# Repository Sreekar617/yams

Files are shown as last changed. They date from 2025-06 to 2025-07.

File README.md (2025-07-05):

## Yet Another Metronome by Sreekar  

Usually when I'm practicing my violin, I like to do a lot of metronome work to keep myself on tempo. However, neither my phone nor my laptop can be heard above the sound of the violin, and it's generally not a good idea to practice quieter because you practice the way you perform.  

Up until this point, my solution was to use the metronome on a Roland Digital Piano, since they're super loud and available for use at my school, where I do most of my practice. The problem is, I don't always practice in the practice rooms, and even then, the rooms with the piano aren't always available.  

My solution is to make a small, portable metronome that can stil get loud enough to hear over my violin playing. The device contains a piezo buzzer, a single Neopixel for visual feedback, an OLED to see the current BPM, and a rotary encoder to change the BPM. To keep things light and small, it's powered by a XIAO RP2040. 

PCB                             |  PCB + Case
:------------------------------:|:---------------------------------:
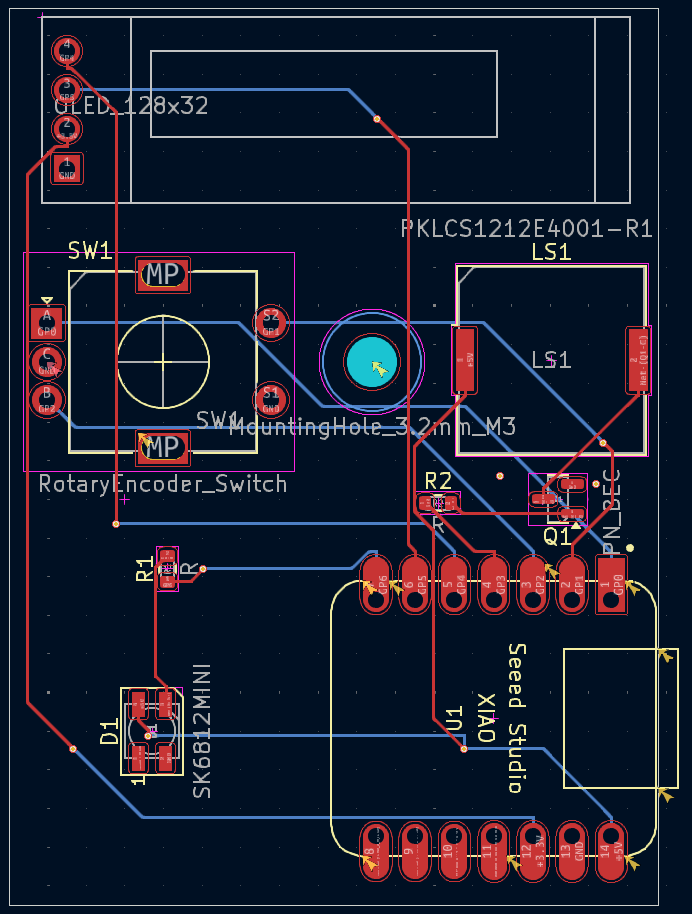
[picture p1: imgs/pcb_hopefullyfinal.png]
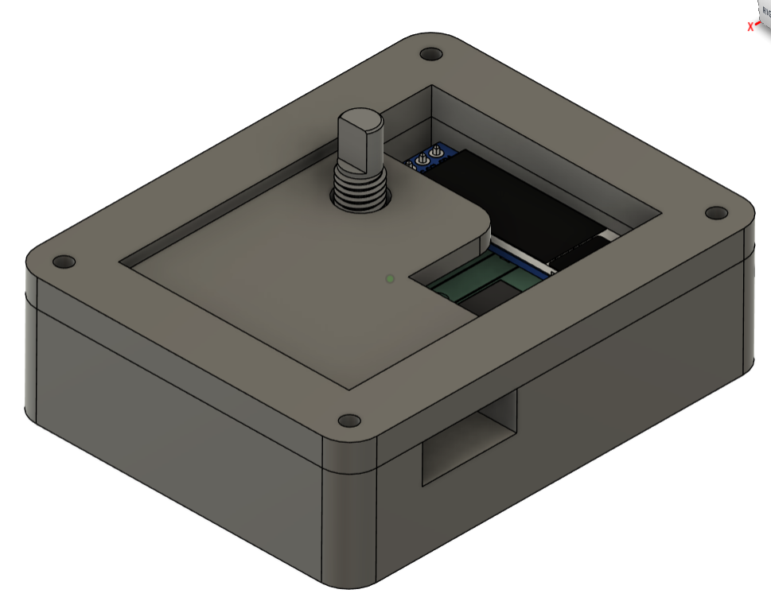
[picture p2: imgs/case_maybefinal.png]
full
| 

BOM:
| Id | Designator | Footprint | Quantity | Designation | Supplier and ref | Link |
| -- | --- | --- | --- | --- | --- | --- |
| 1  | D1 | LED_SK6812MINI_PLCC4_3.5x3.5mm_P1.75mm | 1 | SK6812MINI | C5149201 | https://jlcpcb.com/partdetail/OPSCOOptoelectronics-SK6812MINIE/C5149201  |
| 2  | Q1 | SOT-23 | 1 | Q_NPN_BEC | C2150 | https://jlcpcb.com/partdetail/2507-SS8050_RANGE_200_350/C2150 |
| 3  | J1 | OLED_128x32 | 1 | OLED_128x32 | C5248081 | https://jlcpcb.com/partdetail/HS-HS91L02W2C01/C5248081 |
| 4  | SW1 | RotaryEncoder_Alps_EC11E-Switch_Vertical_H20mm | 1 | RotaryEncoder_Switch  | C202365 | https://jlcpcb.com/partdetail/ALPSALPINE-EC11E18244AU/C202365 |
| 5  | R1 | R_0603_1608Metric | 1 | 300Ω | C23025 | https://jlcpcb.com/partdetail/23752-0603WAF3000T5E/C23025 |
| 6  | R2 | R_0603_1608Metric | 1 | 1000Ω | C51218 | https://jlcpcb.com/partdetail/52231-0603WAD1001T5E/C51218 |
| 7  | U1 | XIAO-Generic-Hybrid-14P-2.54-21X17.8MM | 1 | MOUDLE-SEEEDUINO-XIAO | | https://www.seeedstudio.com/XIAO-RP2040-v1-0-p-5026.html |
| 8  | LS1 | Buzzer_Murata_PKLCS1212E | 1 | PKLCS1212E4001-R1 | C113159 | https://jlcpcb.com/partdetail/MurataElectronics-PKLCS1212E4001R1/C113159 |
| 9  | -- | -- | 4 | M3x20mm Screws | Generic | Source locally |
| 10 | -- | -- | 1 | M3x12mm Screw | Generic | Source locally |
| 11 | -- | -- | 5 | M3 Nuts | Generic | Source locally |
| 12 | -- | -- | 1 | Bottom Case | Generic | Print with Legion |
| 13 | -- | -- | 1 | Top Case | Generic | Print with Legion |
| 14 | -- | -- | 1 | PCB | JLCPCB | Order from JLCPCB |

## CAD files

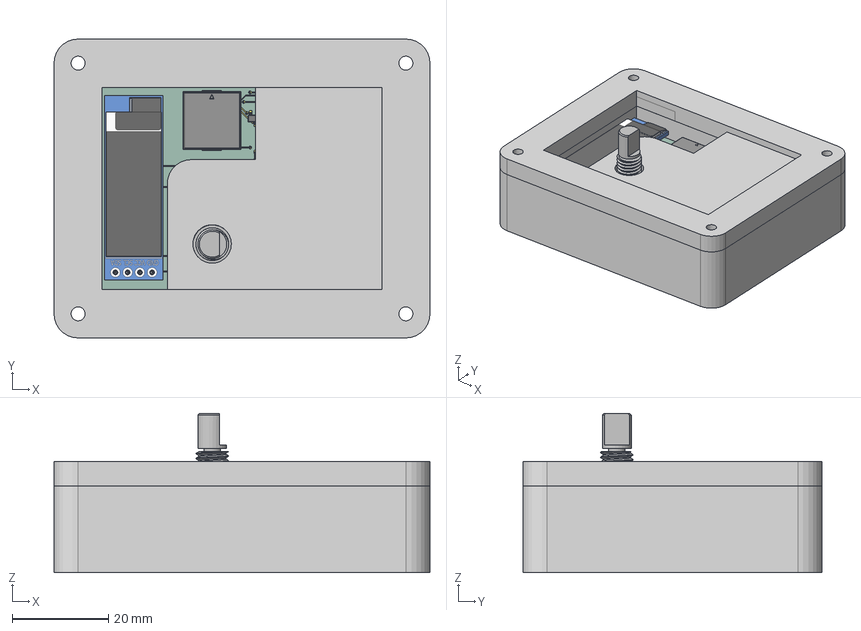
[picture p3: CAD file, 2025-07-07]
CAD/yams_full.step
78.0 x 62.0 x 33.0 mm
SK6812_Mini_1
SK6812_Mini004
SK6812_Mini003
SK6812_Mini005
SK6812_Mini002
SK6812_Mini001
SOT-23
OLED_0.91_128x32
Pin Header 4 x 1 TH 2.54mm Pitch
RESC-0603 x 13
2SD0601A
æè½¬ç¼ç å¨
R_0603_1608Metric x 2
PKLCS1212E4001-R1--3DModel-STEP-56544
yams_metronome_copper
yams_metronome_PCB
type-c v2
smd_button v3
DOUT
DIN
VSS
VDD
smd_button v3(Mirror)

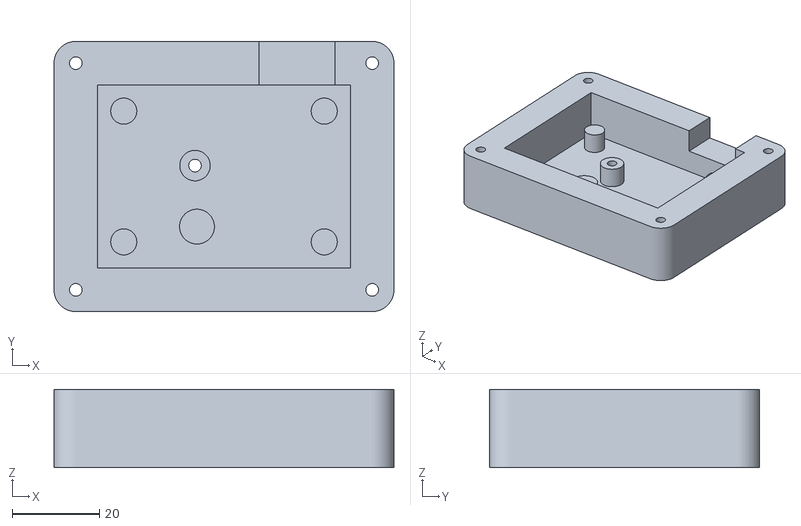
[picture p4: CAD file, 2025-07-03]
production/yams_case_bottom.stl
78.0 x 62.0 x 18.0

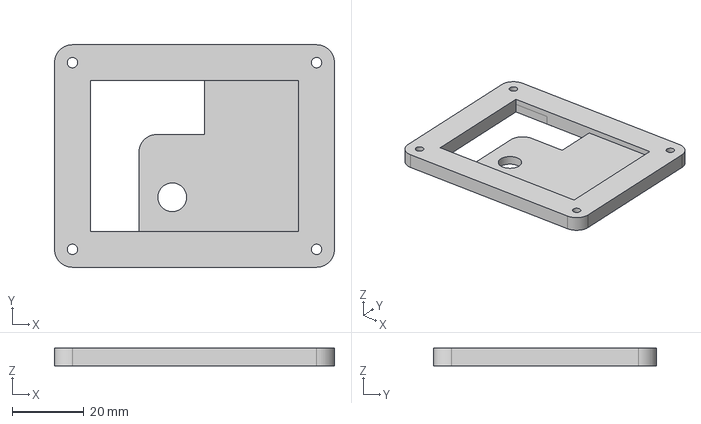
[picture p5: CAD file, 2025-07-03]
CAD/yams_case_top.step
78.0 x 62.0 x 5.00 mm

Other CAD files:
production/yams_case_top.stl
CAD/yams_case_bottom.step

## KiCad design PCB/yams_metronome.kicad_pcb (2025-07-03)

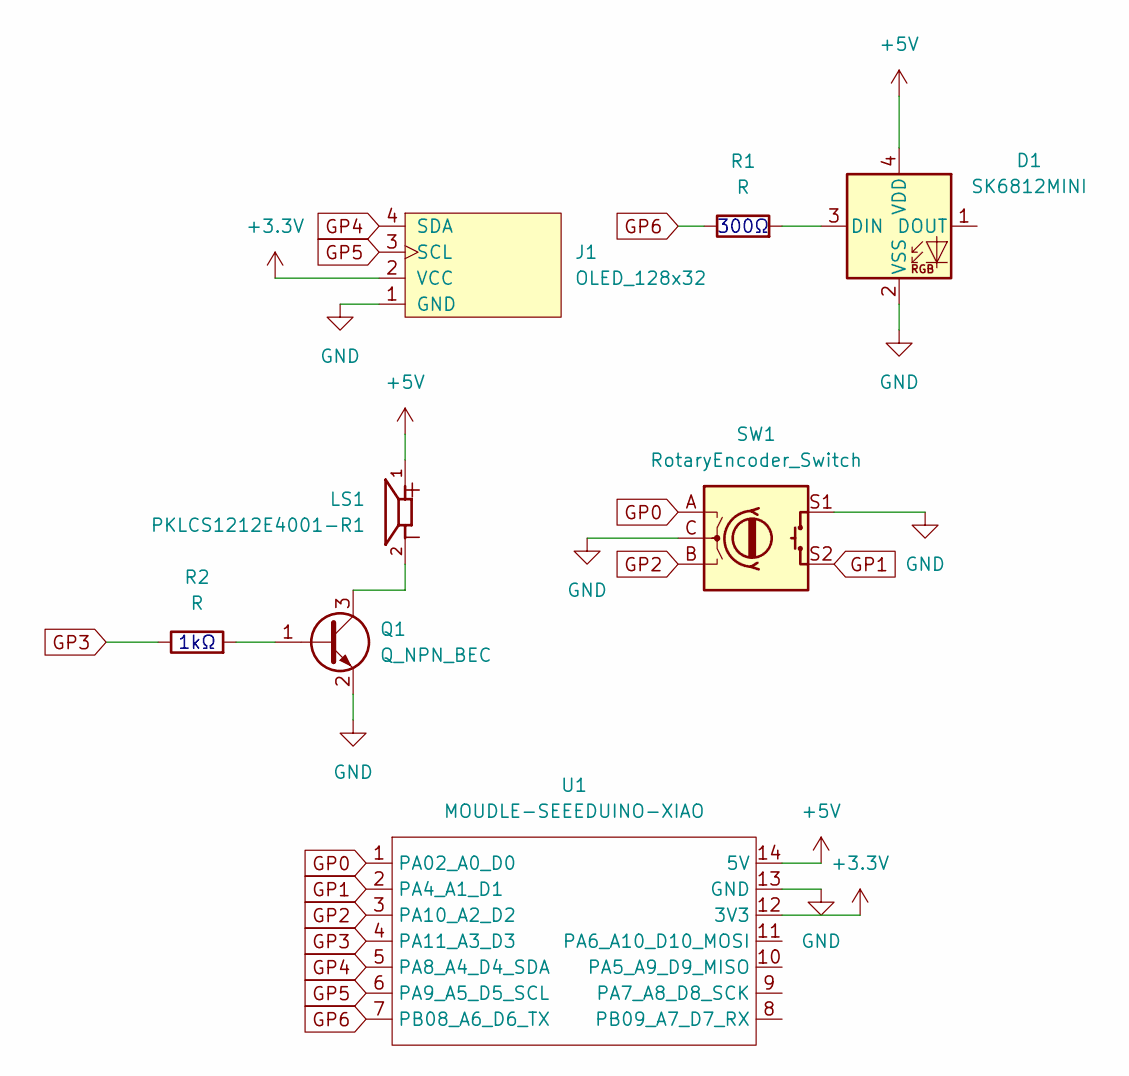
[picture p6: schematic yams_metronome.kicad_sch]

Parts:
D1: SK6812MINI; LED_SK6812MINI_PLCC4_3.5x3.5mm_P1.75mm
J1: OLED_128x32
LS1: PKLCS1212E4001-R1; Buzzer_Murata_PKLCS1212E; PARTREV January 22, 2018
Q1: Q_NPN_BEC; SOT-23
R1, R2: R; R_0603_1608Metric
SW1: RotaryEncoder_Switch; RotaryEncoder_Alps_EC11E-Switch_Vertical_H20mm
U1: MOUDLE-SEEEDUINO-XIAO; XIAO-Generic-Hybrid-14P-2.54-21X17.8MM

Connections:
+3.3V: J1.2 (VCC), U1.12 (3V3)
+5V: D1.4 (VDD), LS1.1, U1.14 (5V)
GND: D1.2 (VSS), J1.1 (GND), Q1.2 (E), SW1.C, SW1.S1, U1.13 (GND)
GP0: SW1.A, U1.1 (PA02_A0_D0)
GP1: SW1.S2, U1.2 (PA4_A1_D1)
GP2: SW1.B, U1.3 (PA10_A2_D2)
GP3: R2.1, U1.4 (PA11_A3_D3)
GP4: J1.4 (SDA), U1.5 (PA8_A4_D4_SDA)
GP5: J1.3 (SCL), U1.6 (PA9_A5_D5_SCL)
GP6: R1.1, U1.7 (PB08_A6_D6_TX)
unnamed: D1.3 (DIN), R1.2
unnamed: Q1.1 (B), R2.2
unnamed: LS1.2, Q1.3 (C)

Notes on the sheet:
300Ω
1kΩ

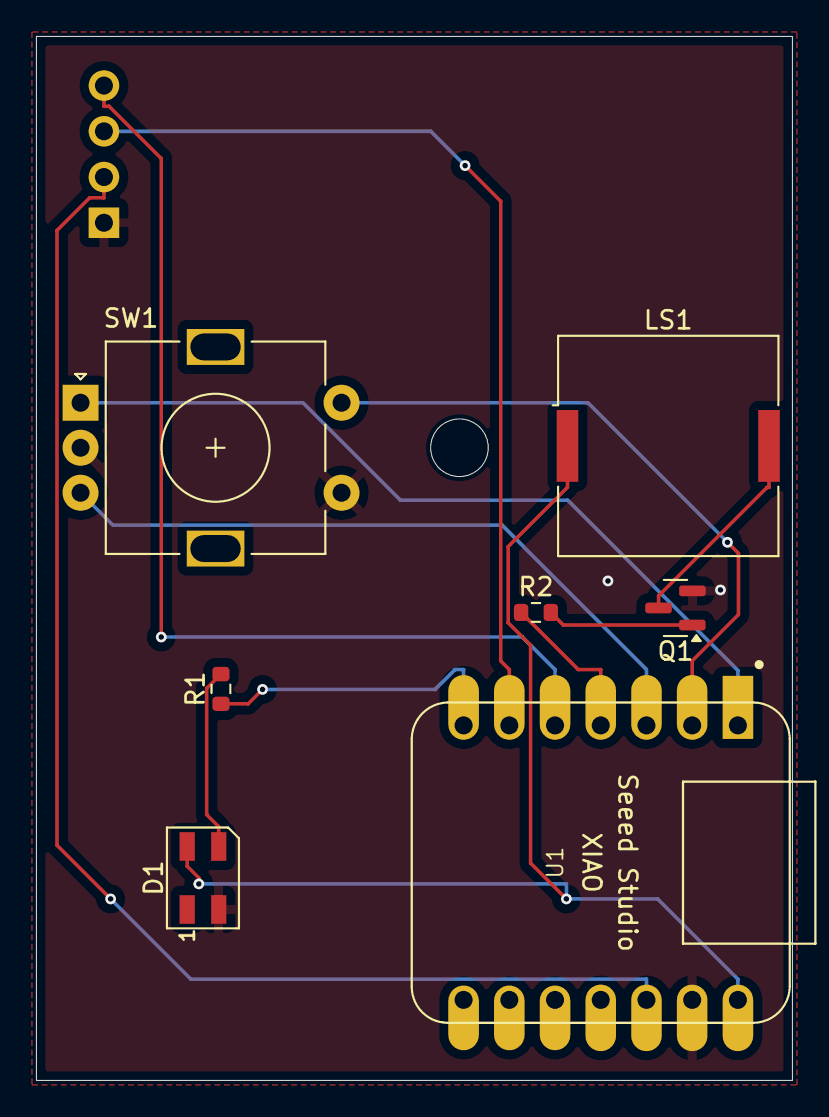
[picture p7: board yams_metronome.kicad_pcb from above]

Board: 2 copper layers, 42.0 x 58.0 mm, 8 parts (0 on the bottom side), 13 nets.

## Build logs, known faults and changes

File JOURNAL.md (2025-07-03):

---
title: "Yet Another Metronome by Sreekar"
author: "Sreekar Ramisetty"
description: "Metronome with rotary encoder and OLED display"
created_at: "2024-06-04"
---
# total time: 18 hours

## June 4th, 2025, 6:32 PM<br>
I have a vision for where I want to take this project, but since I have finals tomorrow i'll just get a basic schematic whipped up (i have no idea what i'm doing)<br>
**literally like 30 seconds spent 😭**

## June 9th, 2025, 3:17 PM<br>
I did not in fact get anything done but finals are over so i can probably actually get started today<br>
hear me out tabletop flat design cause i'm scared of 90°, plate for mx switches and an oled cause i'm overconfident, but first let's get a basic pcb done<br>
wait no hear me out: rotary encoder. to encode your rotary movement. amirite amirite?<br>
**1 hour spent**

## June 12th, 2025, 9:01 PM<br>
ok time to wire up the oled and rotary encoder<br>
zawg how do i power ts<br>
ohhhh now i know the difference between vsys, vbus, and 3v3<br>
it's all wired in the schematic :yay:<br>
now time to find a speaker that's loud and preferably not expensive (good cheap fast ahh)<br>
oops i had the times i spent written in obsidian but not here better add those in<br>
alr i got a somewhat coherent schematic together i'm going to sleep now<BR>
**2 hours spent**<Br>


## June 13th, 2025 12:04 PM<br>
if you're reading the actual markdown for some reason i must apologize for the way i format this<br>
so i want to put an led on here for visual feedback<br>
i could use just a single led or i could use a neopixel :wow:<br>
i think for the led i could just give it power every x ms and put a resistor in front of it<br>
after further research, i've decided to just use a single neopixel<br>
time to go back to the schematic<br>
**1 hour spent 😭**<Br>


## June 15th, 2025 4:30 PM<br>
i guess it's time to pcb all over the place<br>
nvm my schematic has issues<br>
so i guess it's better to power oled with 3v3<br>
and my neopicel wasn't connected to anything somehow<br>
also i guess the buzzer should also use 3v3, honestly the buzzer is what i'm most worried about<br>
schematic should be finished now, it looks so tuff<br>

oh i guess the pins for the buzzer symbol don't match the ones on the footprint, i guess i should just reassign them<br>
**2 hours spent**

## June 18th, 2025 1:12 PM<br>
i fixed the buzzer and made a basic outline of how i want it on paper and on the pcb<Br>
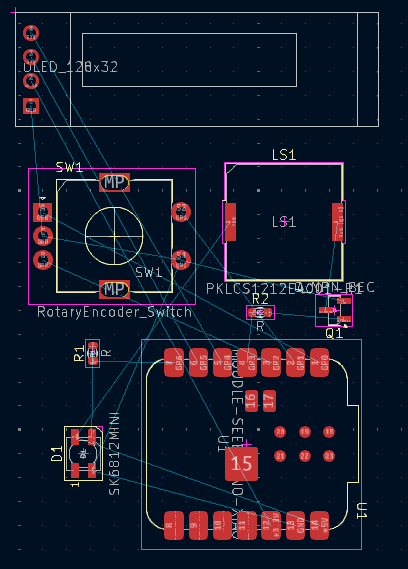
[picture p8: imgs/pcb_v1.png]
<Br>
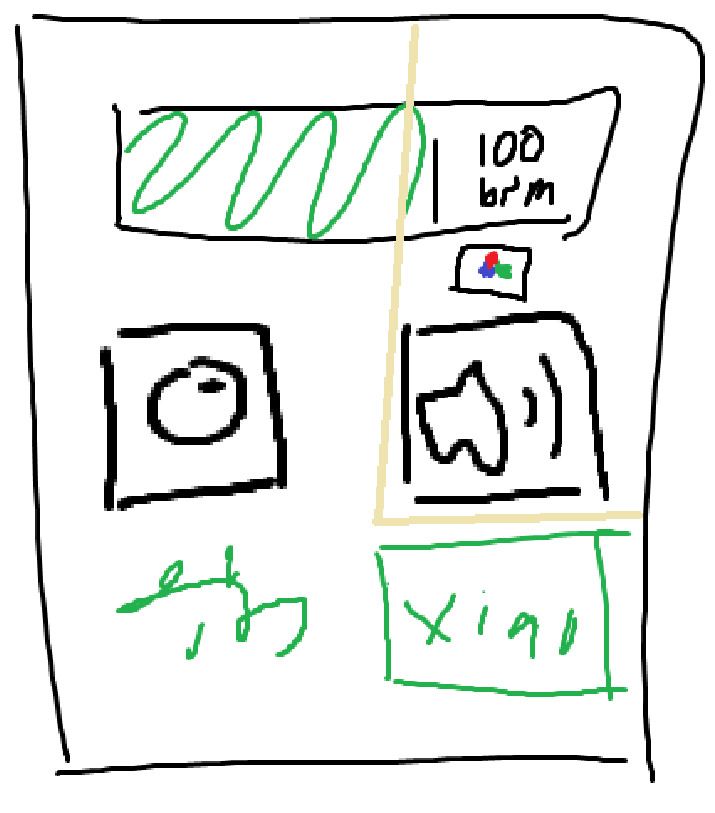
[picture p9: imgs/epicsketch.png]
<br>
**1 hour spent**

## June 22nd, 6:32 PM<Br>
got pcb outline finished and wired
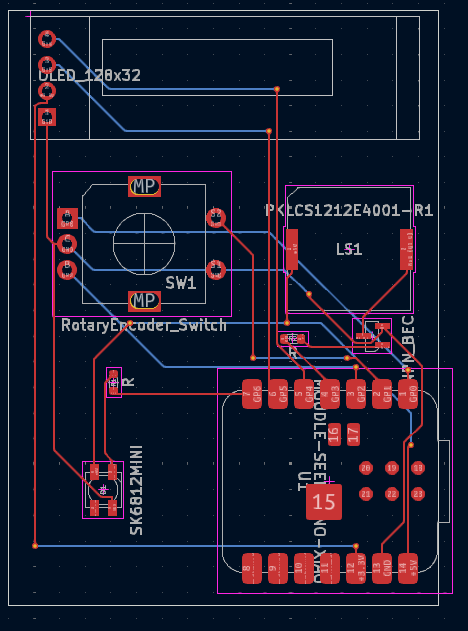
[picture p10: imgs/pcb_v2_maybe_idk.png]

**1 hour spent**

## June 29th, 7:30 PM<br>
ok i should run git push i've been editing ts locally this whole time 😭<br>
anyway i'm locking in now to make the case<br>
okay i think it'll be more stable if i make a round cutout for the rotary encoder instead of just having it completely exposed<br>
and i should also have a square border that is actually connected to the "plate" to give it some more stability<br>
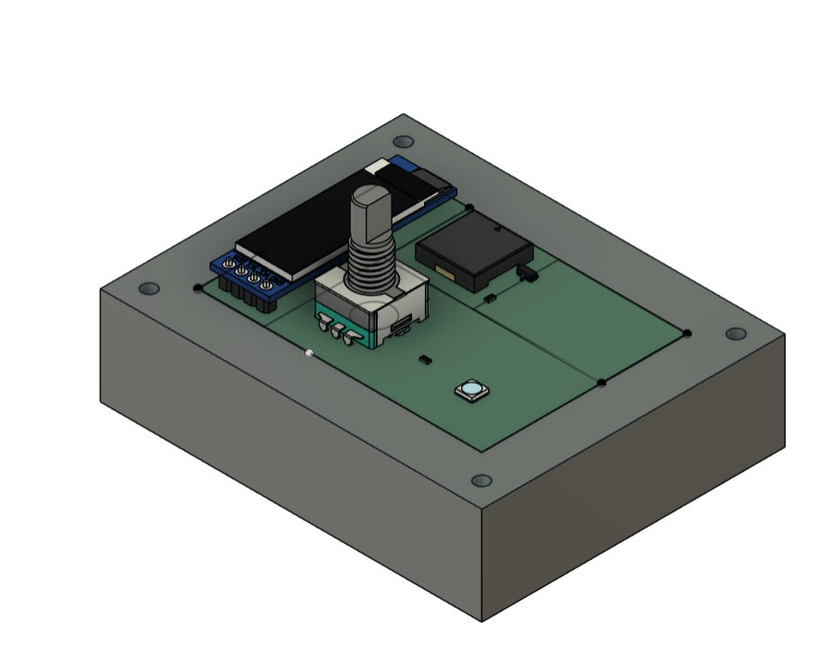
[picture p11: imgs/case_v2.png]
<br>
wait i was going to sandwich mount it like a keyboard but i don't have mx switches, just a rotary encoder<br>
how do i mount ts 😭<br>
**3 hours spent**

## June 30th, 2:34 PM<br>
i thought about it and i looked at the mounting styles website and i think if i make a kind of tray mount style case it'll be fine<br>
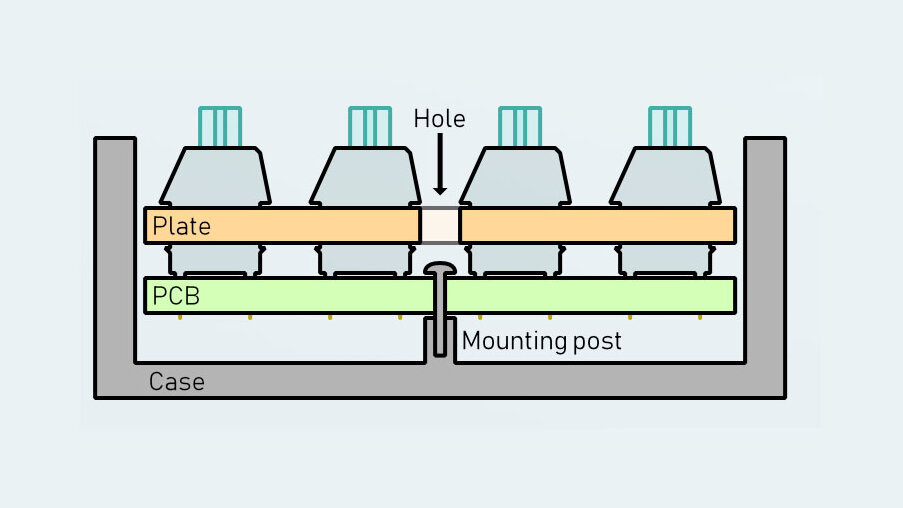
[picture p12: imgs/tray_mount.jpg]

so in my case the "plate" doesn't hold up the pcb in any way, it's just to cover and protect the pcb, so i'll have a couple more posts in the corners to hold it up, and probably something under the encoder to give it stability<br>
i made some slight adjustments to the pcb to give the screw a bit of clearance<br>
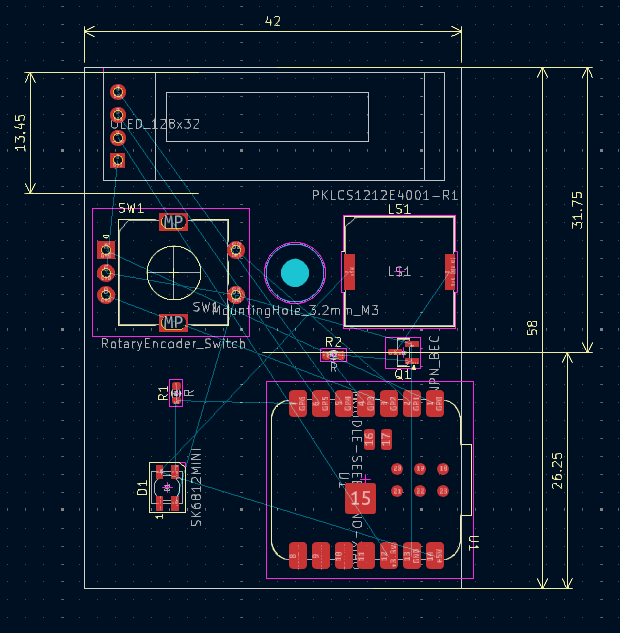
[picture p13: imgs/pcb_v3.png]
<br>
ok i'll just edit my sketch and go to sleep
**2 hours spent**

## July 1st, 3:22 PM<br>
i want to get ts finished today, luckily it's just continuing manual labor from yesterday  
okay i got the case put together  
  
so this is in two pieces, the bottom case and a top covering.  
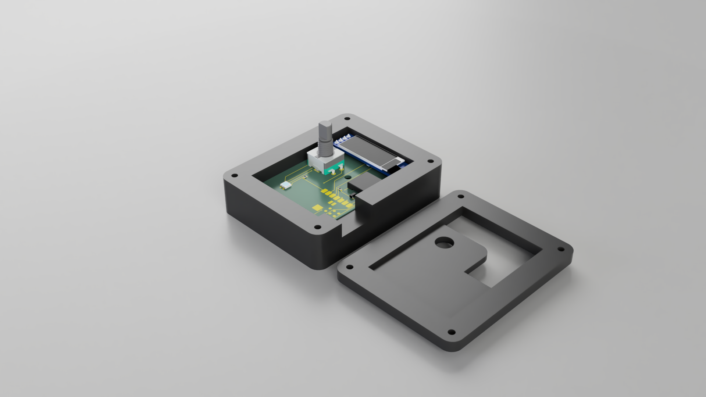
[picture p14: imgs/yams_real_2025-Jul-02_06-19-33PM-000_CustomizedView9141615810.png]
alt extxusdcgfsihguofijdhsu
  
there's a hole for the rotary encoder, and another hole on the side for power delivery to the xiao  
the pcb is held up with supports at the bottom of the case. there's a "post" in each corner, plus one directly under the rotary   encoder and one approximately in the middle to screw into.  
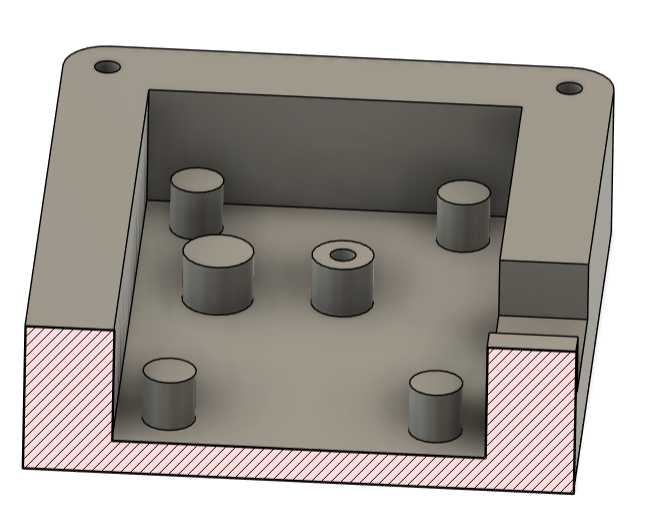
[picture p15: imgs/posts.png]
  
agh i forgot about firmware see you tomorrow  
**2 hours spent**

## July 2st, 1:10 PM<br>
okay firmware should be pretty simple. i think i can even get away with using qmk cause that's what i'm familiar with  
ok so i am definitely not using qmk  
oh yeah i added a ground pour  
  
after much research and docs reading, i think i got a probably working firmware:  
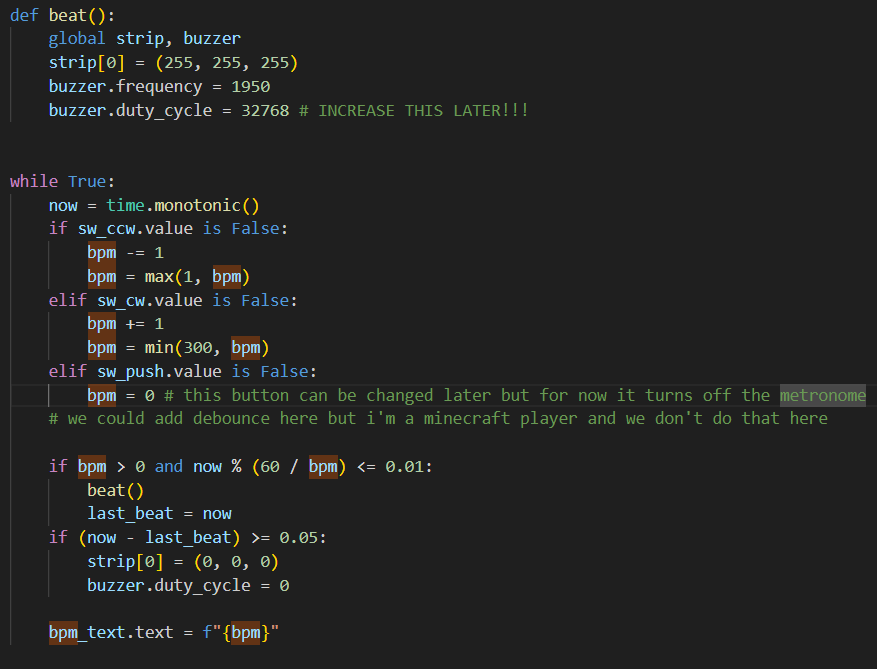
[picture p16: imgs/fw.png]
i aint reading allat
  
you change the bpm with the rotary encoder, and push on it to turn off the metronome  
when a beat happens, the piezo buzzer chirps and the neopixel flashes  
yeah that's pretty much it :heavysob:  
thanks for reading make sure to like and subscribe  
**3 hours spent**

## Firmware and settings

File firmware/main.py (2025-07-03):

import time
import board
import displayio
import terminalio
from adafruit_display_text import label
import adafruit_displayio_ssd1306
import busio
import digitalio
import neopixel
import pwmio

displayio.release_displays()
i2c = busio.I2C(scl=board.GP5, sda=board.GP4)
display_bus = displayio.I2CDisplay(i2c, device_address=0x3C)
display = adafruit_displayio_ssd1306.SSD1306(display_bus, width=128, height=32)
main_group = displayio.Group()

buzzer = pwmio.PWMOut(board.GP3, duty_cycle=0, frequency=440, variable_frequency=True)


sw_ccw = digitalio.DigitalInOut(board.GP0)
sw_ccw.direction = digitalio.Direction.INPUT
sw_ccw.pull = digitalio.Pull.UP 

sw_cw = digitalio.DigitalInOut(board.GP2)
sw_cw.direction = digitalio.Direction.INPUT
sw_cw.pull = digitalio.Pull.UP

sw_push = digitalio.DigitalInOut(board.GP1)
sw_push.direction = digitalio.Direction.INPUT
sw_push.pull = digitalio.Pull.UP

strip = neopixel.NeoPixel(board.GP6, 1, brightness=0.2, auto_write=True) # INCREASE THIS LATER!!!
strip[0] = (0, 0, 0) 

bpm = 120
last_beat = time.monotonic()
bpm_text = label.Label(terminalio.FONT, text=f"{bpm}", scale=2, x=0, y=16)
main_group.append(bpm_text)

now = 0


def beat():
    global strip, buzzer
    strip[0] = (255, 255, 255)
    buzzer.frequency = 1950
    buzzer.duty_cycle = 32768 # INCREASE THIS LATER!!!


while True:
    now = time.monotonic()
    if sw_ccw.value is False:
        bpm -= 1
        bpm = max(1, bpm)
    elif sw_cw.value is False:
        bpm += 1
        bpm = min(300, bpm)
    elif sw_push.value is False:
        bpm = 0 # this button can be changed later but for now it turns off the metronome
    # we could add debounce here but i'm a minecraft player and we don't do that here

    if bpm > 0 and now % (60 / bpm) <= 0.01:
        beat()
        last_beat = now
    if (now - last_beat) >= 0.05:
        strip[0] = (0, 0, 0)
        buzzer.duty_cycle = 0

    bpm_text.text = f"{bpm}"

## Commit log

2025-06-13 i think that's how you do it
    [yams_metronome.kicad_sch]
2025-07-03 uploaded all the pcb and cad files
    [yams_case_bottom.step, yams_case_bottom.stl, yams_case_top.step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]
2025-07-07 added full model
    [yams_full.step]
